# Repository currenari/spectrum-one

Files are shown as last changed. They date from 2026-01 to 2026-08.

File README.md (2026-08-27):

# Spectrum One

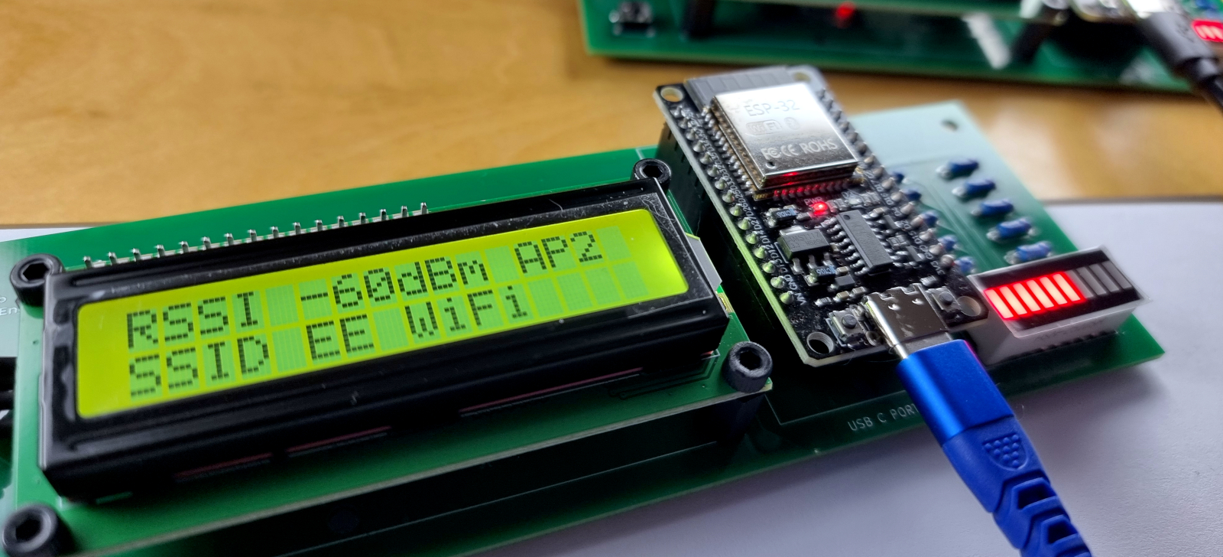
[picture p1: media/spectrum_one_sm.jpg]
Spectrum One


Spectrum One is a compact ESP32-based WiFi activity monitor that visualises nearby WiFi activity using a 16×2 LCD and a 10-segment LED bar.

It works by running repeated WiFi scans and turning the results into something you can actually see — live signal bars, changing numbers, blinking LEDs. The values shown are derived from WiFi RSSI and are intended for visualisation and comparison, not calibrated RF measurement.

This repository contains the reference implementation of the device.

---

## Open Hardware Certification

<a href="https://certification.oshwa.org/uk000086.html">
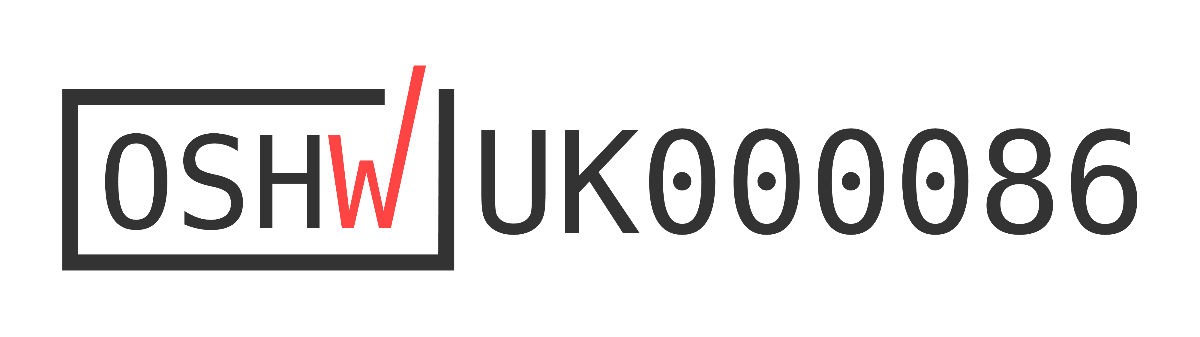
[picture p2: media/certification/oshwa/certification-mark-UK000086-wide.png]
OSHWA certification UK000086
  
</a>

**OSHWA UID:** UK000086  
Full record: `CERTIFICATION.md`  
Certified hardware version: 0.1.0

---

## Repository Contents

The repository is organised by release version and contains:

**binaries/**  
Versioned reference firmware binaries for flashing Spectrum One hardware.

**firmware/**  
ESP-IDF firmware source code.

**hardware/**  
KiCad schematics, PCB layouts, symbols, footprints, and fabrication outputs.

**docs/**  
Repository documentation, technical notes, and [ESP32 WiFi Activity Monitor PDF Book (Direct Download)](https://github.com/currenari/spectrum-one/raw/main/docs/ESP32%20WiFi%20Activity%20Monitor.pdf).

**media/**  
Images and diagrams used by the repository documentation.

---

## Hardware Assembly

This repository provides assembly documentation sufficient to reproduce the open hardware design.

General assembly information is provided in:

`ASSEMBLY.md`

Version-specific assembly notes are located under:

- `hardware/v0.1.0/ASSEMBLY.md`

---

## Project Scope

This repository contains the open hardware design files, firmware source code, reference binaries, and technical documentation required to reproduce Spectrum One.

Extended development notes and technical writing are published at:

https://currenari.com

---

## Licensing

Licensing is separated by material type:

- **Firmware source code and binaries**  
  MIT License

- **Hardware design files**  
  CERN Open Hardware Licence v2.0 – Strongly Reciprocal (CERN-OHL-S-2.0)

- **Repository documentation and media**  
  Creative Commons Attribution 4.0 International (CC BY 4.0)

Full licensing terms are defined in `LICENSE.md`.

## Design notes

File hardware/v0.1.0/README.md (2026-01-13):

# Spectrum One Hardware v0.1.0

This folder contains the KiCad design files for Spectrum One hardware release v0.1.0.

Contents include:
- Schematic
- PCB layout
- Custom symbols and footprints
- Fabrication outputs (Gerbers and drill files)

The Gerbers in hardware/v0.1.0/gerbers are the release fabrication set for this version.

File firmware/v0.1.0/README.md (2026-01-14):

# Spectrum One Firmware v0.1.0

This directory contains the firmware source for Spectrum One release v0.1.0,
implemented as an ESP-IDF application for the ESP32 platform.

The firmware is built and flashed using Espressif’s ESP-IDF toolchain, which is
the supported and documented development environment for this project.

Its function is to perform repeated WiFi scans and visualise observed activity
using an LCD and LED bar display.

## Build environment

ESP-IDF is the supported build environment.

## Notes

This firmware is intended to observe and visualise WiFi activity.
It does not provide calibrated RF measurements.

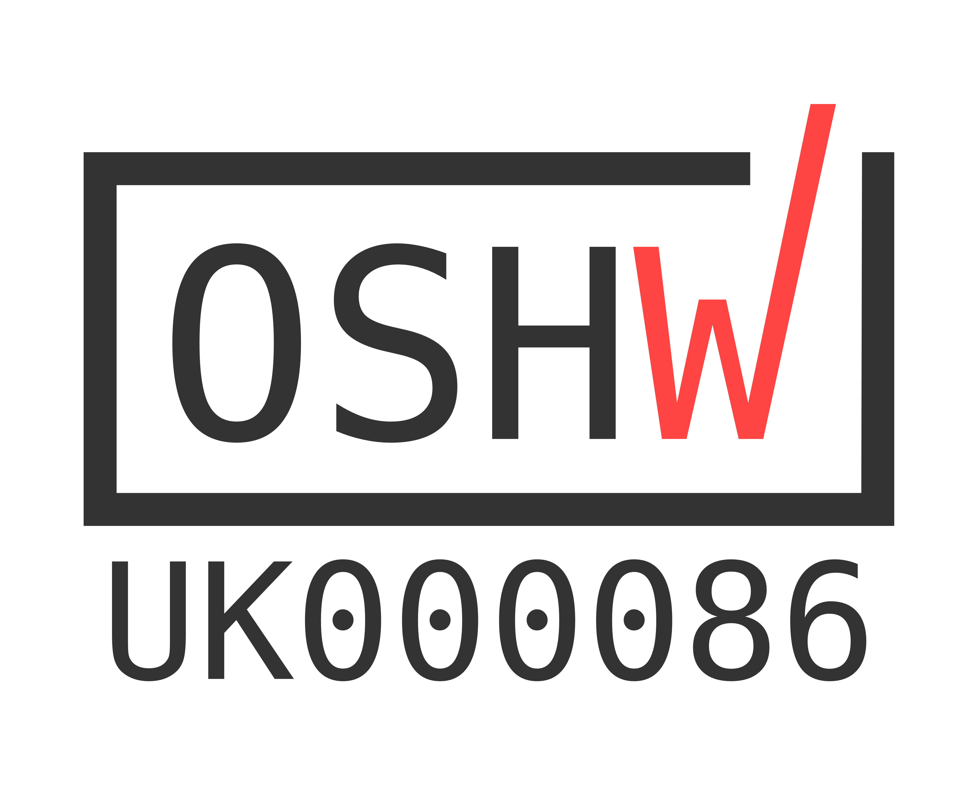
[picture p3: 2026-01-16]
media/certification/oshwa/certification-mark-UK000086-stacked.png

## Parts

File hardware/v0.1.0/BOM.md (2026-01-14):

# Spectrum One – Bill of Materials

This document lists the physical components used in the Spectrum One reference hardware.

The BOM reflects the exact parts and construction choices used during development and validation.
It is provided to support reproducibility of the hardware design. Equivalent parts with matching
specifications may be used unless otherwise noted.

---

## ESP32 Development Board (1×)

- Type: ESP32 Dev Kit V1
- Module: ESP32-WROOM-32
- Form factor: 30-pin
- USB interface: USB-C

---

## Pin Headers for ESP32 Development Board (2×)

- Type: pin header
- Pitch: 2.54 mm
- Positions: 15-pin
- Rows: single row
- Mounting: through-hole
- Use: PCB to ESP32 development board connection

---

## LCD 1602 Display with I2C Backpack (1×)

- Display type: LCD 1602
- Controller: HD44780 compatible
- Display format: 16 characters × 2 lines
- Native interface: parallel (HD44780)

### I2C backpack

- Controller: PCF8574
- Interface: I2C
- Pinout: GND, VCC, SDA, SCL
- Default I2C address: 0x27
- Address selection: configurable via A0, A1, A2 jumpers

---

## JST XH Connector and Cable Assembly

### PCB-mounted connector (1×)

- Type: JST XH series
- Pitch: 2.54 mm
- Positions: 4-pin
- Mounting: through-hole, soldered directly to the PCB
- Use: LCD power and I2C connection

### Cable assembly (1×)

- Type: JST XH compatible cable
- Configuration: 4-pin
- One end: JST XH housing (mates with PCB connector)
- Other end: individual wires soldered directly to the LCD I2C backpack
- Note: no connector fitted on the LCD side in the reference build

---

## LED Bar Graph Display (1×)

- Part type: LED bar graph
- Model: HSN-2510SR
- Colour: red
- Segment count: 10 independent LEDs
- Pin count: 20 pins (10 per side)
- Electrical configuration: no common anode, no common cathode

---

## Resistors (10×)

- Resistance: 220 Ω
- Tolerance: 5 percent
- Power rating: 0.25 W
- Type: through-hole axial

---

## Capacitor (1×)

- Capacitance: 100 nF
- Type: ceramic
- Package: through-hole
- Purpose: local supply decoupling

---

## Push Button (1×)

- Type: momentary tactile switch
- Configuration: SPST, normally open
- Package: through-hole, 6 × 6 mm

---

## Display Mounting Hardware

### Nylon standoffs (4×)

- Type: hexagonal PCB standoff
- Material: nylon
- Thread: M3, female–female
- Length: 10 mm
- Use: spacing and mounting of LCD module above PCB

### Nylon screws (8×)

- Type: socket cap head screw
- Material: nylon
- Thread: M3
- Length: 6 mm
- Drive: hex (Allen)
- Use: fixing LCD module to nylon standoffs

---

## LCD I2C Address Note

The reference build uses an LCD1602 with a PCF8574 I2C backpack configured at address `0x27`.

Some visually identical LCD backpacks use address `0x3F` instead.
If the display remains blank, change the firmware LCD address accordingly and rebuild.

This behaviour is covered in detail in the firmware documentation.

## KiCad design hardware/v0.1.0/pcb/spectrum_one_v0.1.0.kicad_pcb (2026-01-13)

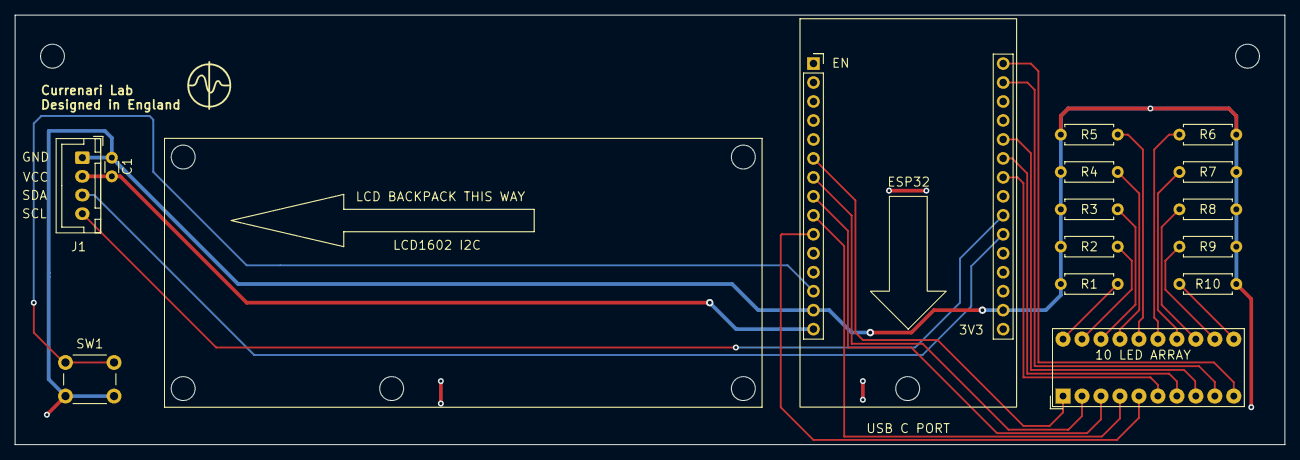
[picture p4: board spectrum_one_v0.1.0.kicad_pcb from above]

Board: 2 copper layers, 170.0 x 57.5 mm, 15 parts (0 on the bottom side), 25 nets.

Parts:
10 LED ARRAY: HLCP-J100_2; HLCP-J100
C1: C; C_Disc_D3.0mm_W1.6mm_P2.50mm
ESP32: Copper Keepout Zone; ESP32_DEVKIT_V1_DUAL_HEADER_SOCKET_VERTICAL
J1: LCD_I2C_XH4_PCBSocket; JST_XH_B4B-XH-A_1x04_P2.50mm_Vertical
R1, R2, R3, R4, R5, R6, R7, R8, R9, R10: R; R_Axial_DIN0207_L6.3mm_D2.5mm_P7.62mm_Horizontal
SW1: SW_Tact_6x6mm_H5mm_PxPy; SW_Tact_6x6mm_H5mm_PxPy_footprint

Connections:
/VCC: C1.2, ESP32.15 (VIN), J1.2 (VCC)
GND: C1.1, ESP32.14 (GND), ESP32.29 (GND), J1.1 (GND), R1.1, R2.1, R3.1, R4.1, R5.1, R6.1, R7.1, R8.1, R9.1, R10.1, SW1.2
unnamed: 10 LED ARRAY.11 (K), R10.2
unnamed: 10 LED ARRAY.12 (K), R9.2
unnamed: 10 LED ARRAY.13 (K), R8.2
unnamed: 10 LED ARRAY.14 (K), R7.2
unnamed: 10 LED ARRAY.15 (K), R6.2
unnamed: 10 LED ARRAY.16 (K), R5.2
unnamed: 10 LED ARRAY.17 (K), R4.2
unnamed: 10 LED ARRAY.18 (K), R3.2
unnamed: 10 LED ARRAY.19 (K), R2.2
unnamed: 10 LED ARRAY.20 (K), R1.2
unnamed: ESP32.24 (GPIO17), J1.4 (SCL)
unnamed: ESP32.25 (GPIO16), J1.3 (SDA)
unnamed: ESP32.13 (GPIO13), SW1.1
unnamed: 10 LED ARRAY.6 (A), ESP32.22 (GPIO18)
unnamed: 10 LED ARRAY.7 (A), ESP32.21 (GPIO19)
unnamed: 10 LED ARRAY.8 (A), ESP32.20 (GPIO21)
unnamed: 10 LED ARRAY.9 (A), ESP32.17 (GPIO22)
unnamed: 10 LED ARRAY.10 (A), ESP32.16 (GPIO23)
unnamed: 10 LED ARRAY.3 (A), ESP32.8 (GPIO25)
unnamed: 10 LED ARRAY.4 (A), ESP32.9 (GPIO26)
unnamed: 10 LED ARRAY.5 (A), ESP32.10 (GPIO27)
unnamed: 10 LED ARRAY.1 (A), ESP32.6 (GPIO32)
unnamed: 10 LED ARRAY.2 (A), ESP32.7 (GPIO33)

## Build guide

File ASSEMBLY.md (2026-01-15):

This repository provides minimal assembly documentation
to support reproduction of the Spectrum One hardware.

Version-specific assembly notes:
- hardware/v0.1.0/ASSEMBLY.md

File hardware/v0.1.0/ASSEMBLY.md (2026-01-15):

# Spectrum One PCB Assembly  
Hardware version v0.1.0

This document describes PCB level assembly requirements for the Spectrum One hardware.

## Scope
This document covers PCB level assembly.

Firmware, electrical behaviour, calibration, and end user operation are out of scope.

## Bill of Materials
All components, values, quantities, and reference designators are defined in the Bill of Materials.

**The BOM is the single source of truth for parts.**

See:
- `hardware/v0.1.0/BOM.md`

This assembly document does not repeat the component list in order to avoid duplication and inconsistency.

## Board overview
- 2 layer FR4 PCB
- ESP32 development module installed using soldered pin header sockets
- Power supplied via the ESP32 module USB C connector (5 V)
- 3.3 V logic throughout the board

## Assembly notes

### ESP32 module mounting
- Pin header sockets are soldered to the PCB
- The ESP32 module is inserted into the sockets after soldering
- The ESP32 module itself is not soldered directly to the PCB

### LED bar array orientation
- The LED bar is a single multi LED package with a fixed pinout
- The component must be installed in the correct orientation as a whole
- Orientation is defined by the PCB silkscreen and the package pin 1 marking
- Installing the LED bar in reverse orientation will prevent correct operation

### LCD backpack connection
- LCD1602 I2C backpacks may use different pinout arrangements depending on manufacturer
- Pin order must be verified before any direct electrical connection
- The recommended approach is to connect the LCD backpack to the PCB using four wires terminated with a JST connector
- This avoids pinout mismatch issues and allows easier replacement

### LCD mounting
- The LCD module is mounted with a 10 mm standoff distance at four mounting points
- Ensure the LCD is mechanically supported and not under strain after installation

### Orientation
- ESP32 module orientation follows the PCB silkscreen outline and arrow
- LCD related connectors must follow PCB silkscreen markings
- Pin 1 indicators must be respected where present

### Polarised components
- Polarised components must be oriented according to PCB markings

### Non polarised components
- Resistors and other non polarised passives may be installed in either orientation
- The capacitor located adjacent to the JST connector is non polarised and may be installed in either orientation

## Mechanical considerations
- Ensure pin header sockets are aligned and seated squarely before soldering
- Insert the ESP32 module only after all socket joints have cooled
- Avoid excessive heat on connectors, headers, and JST wiring
- Inspect all solder joints for wetting and continuity

## Reference files
- PCB layout: `pcb/`
- Schematic: `schematic/`
- Footprints: `footprints/`
- Symbols: `symbols/`
- Gerbers: `gerbers/`
- BOM: `BOM.md`

All reference files listed above correspond to hardware version v0.1.0.

## Assembly reference images

### Assembled PCB
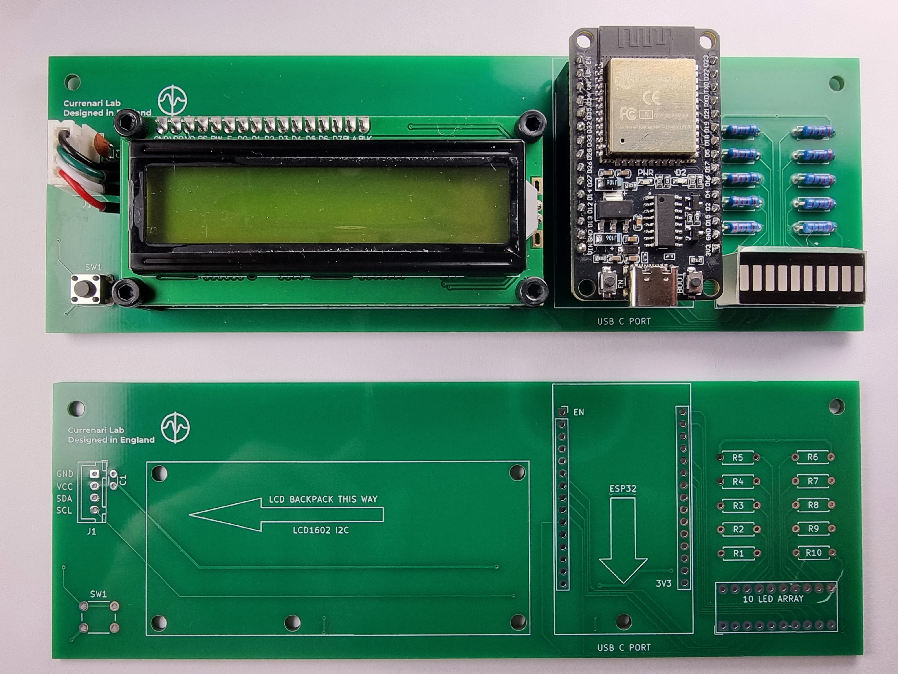
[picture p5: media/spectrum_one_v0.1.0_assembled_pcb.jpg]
Spectrum One assembled PCB v0.1.0


This image shows a fully assembled Spectrum One PCB for hardware version v0.1.0.

### Reference parts set
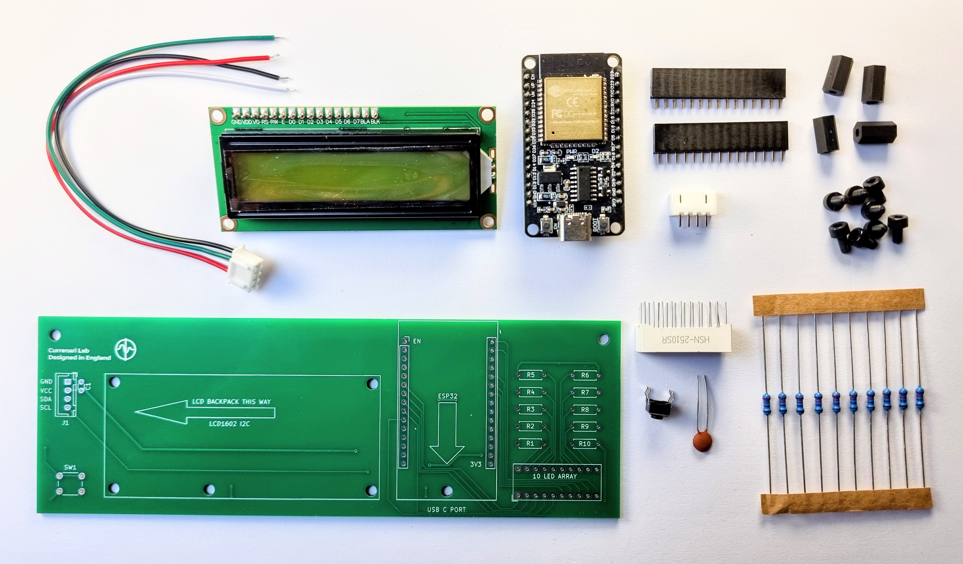
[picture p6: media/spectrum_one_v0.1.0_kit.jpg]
Spectrum One reference parts set v0.1.0


This image shows the physical components used in the reference build.
Equivalent parts meeting the BOM specifications may be used.

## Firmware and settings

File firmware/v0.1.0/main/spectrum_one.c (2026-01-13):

/**
 * @file spectrum_one.c
 *
 * Main application code for Spectrum One.
 *
 * Handles UI state, button input, display updates, and coordination
 * between WiFi scan results, the LCD, and the LED bar.
 *
 * UI modes:
 *   0 : Strongest access point (browse overlay when active)
 *   1 : Total power (SUM)
 *   2 : Field level
 *
 * Additional state flags control browsing and follow behaviour.
 *
 * Compile-time options below allow different timeout and interaction
 * behaviours to be tested.
 */


/*
 * Button response timing
 *
 * Button input is polled and debounced, then handled in the main loop.
 * This keeps UI state changes simple but adds noticeable latency.
 *
 * Delay comes from:
 * - Poll interval and debounce
 * - Event handling tied to the main loop timing
 *
 * Worst case response can be close to the main loop delay.
 *
 * If faster response is needed in a future revision:
 * - Lower debounce or poll interval
 * - Shorten the main loop delay
 * - Handle button events directly in the button task
 */



#include <stdio.h>
#include <stdbool.h>
#include <string.h>

#include "freertos/FreeRTOS.h"
#include "freertos/task.h"
#include "freertos/queue.h"

#include "esp_log.h"
#include "driver/gpio.h"

#include "led_bar.h"
#include "wifi_scan.h"
#include "lcd1602.h"
#include "wifi_one_math.h"
#include "config.h"

static const char *TAG = "SPECTRUM_ONE";

// -----------------------------------------------------------------------------
// Button and timing configuration
// -----------------------------------------------------------------------------

#define BTN_GPIO               SO_BUTTON_GPIO

#define BUTTON_POLL_MS         10
#define DEBOUNCE_TICKS         3
#define LONG_PRESS_MS          600

// -----------------------------------------------------------------------------
// UI behaviour options (compile-time)
// -----------------------------------------------------------------------------

/*
 * Main idle timeout.
 * When enabled, the UI returns to the Field screen after inactivity.
 */
#define UI_IDLE_TIMEOUT_ENABLED     0
#define UI_IDLE_TIMEOUT_MS          8000

/*
 * Browse timeout.
 * When enabled, browse mode exits automatically after a delay.
 */
#define UI_BROWSE_TIMEOUT_ENABLED   1
#define UI_BROWSE_TIMEOUT_MS        5000

/*
 * SUM screen timeout.
 * Independent timeout for the SUM screen only.
 */
#define UI_SUM_TIMEOUT_ENABLED      0
#define UI_SUM_TIMEOUT_MS           15000

/*
 * Short-click behaviour on SUM screen.
 * When enabled, a short click exits SUM directly to Field.
 */
#define UI_SUM_SHORTCLICK_EXITS     0

/* Internal compatibility mappings */
#define AP_BROWSE_TIMEOUT_MS        UI_BROWSE_TIMEOUT_MS
#define MAIN_IDLE_TIMEOUT_MS        UI_IDLE_TIMEOUT_MS

// -----------------------------------------------------------------------------
// UI event queue
// -----------------------------------------------------------------------------

typedef enum {
    UI_EVT_SHORT_CLICK = 0,
    UI_EVT_LONG_PRESS  = 1
} ui_evt_type_t;

typedef struct {
    ui_evt_type_t type;
    TickType_t    tick;
} ui_evt_t;

static QueueHandle_t ui_evt_q = NULL;

// -----------------------------------------------------------------------------
// UI state
// -----------------------------------------------------------------------------

/* 0 = strongest, 1 = SUM, 2 = Field */
static int ui_mode = 2;

static int        current_ap_index    = 0;
static bool       ap_browse_active    = false;
static TickType_t ap_browse_last_tick = 0;

static TickType_t last_activity_tick  = 0;
static TickType_t sum_enter_tick      = 0;

static wifi_scan_result_t last_scan_result;
static bool               last_scan_valid = false;

/* Follow mode state */
static bool follow_mode     = false;
static int  follow_ap_index = -1;
static char follow_ssid[33];

/* Button debounce and press tracking */
static int        btn_stable_state = 1;
static int        btn_debounce_cnt = 0;
static bool       btn_down         = false;
static bool       btn_long_handled = false;
static TickType_t btn_down_tick    = 0;

// -----------------------------------------------------------------------------
// Button handling
// -----------------------------------------------------------------------------

static void button_init(void)
{
    gpio_config_t io_conf = {
        .mode = GPIO_MODE_INPUT,
        .pull_up_en = GPIO_PULLUP_ENABLE,
        .pull_down_en = GPIO_PULLDOWN_DISABLE,
        .intr_type = GPIO_INTR_DISABLE,
        .pin_bit_mask = 1ULL << BTN_GPIO
    };

    gpio_config(&io_conf);

    btn_stable_state = 1;
    btn_debounce_cnt = 0;
    btn_down         = false;
    btn_long_handled = false;
}

static void ui_evt_send(ui_evt_type_t type, TickType_t now)
{
    if (ui_evt_q == NULL) return;

    ui_evt_t e = { .type = type, .tick = now };

/* Queue overflow drops events under heavy input */
    (void)xQueueSend(ui_evt_q, &e, 0);
}

// -----------------------------------------------------------------------------
// Display update logic
// -----------------------------------------------------------------------------

static void refresh_display(void)
{
    if (!last_scan_valid) {
        lcd_show_status("Scanning", "Please wait");
        led_bar_set_level(0);
        return;
    }

    /* Follow mode overrides all other UI states */
    if (follow_mode) {
        if (last_scan_result.ap_count == 0 ||
            follow_ap_index < 0 ||
            follow_ap_index >= last_scan_result.ap_count) {

            lcd_show_status("Locked AP", "Lost");
            led_bar_set_level(0);
            return;
        }

        const wifi_ap_info_t *ap = &last_scan_result.ap_records[follow_ap_index];

        lcd_show_scan_result(ap->rssi, follow_ap_index + 1, ap->ssid);
        led_bar_set_level(wifi_one_led_from_ap_rssi(ap->rssi));
        return;
    }

    if (last_scan_result.ap_count == 0) {
        lcd_show_status("No APs", "Scan again");
        led_bar_set_level(0);
        return;
    }

    int   led_level = 0;
    float field_nw  = wifi_one_field_from_mw(last_scan_result.total_mw);

    if (ui_mode == 0) {
        if (ap_browse_active) {
            if (current_ap_index >= last_scan_result.ap_count) {
                current_ap_index = 0;
            }

            const wifi_ap_info_t *ap =
                &last_scan_result.ap_records[current_ap_index];

            lcd_show_scan_result(ap->rssi,
                                 current_ap_index + 1,
                                 ap->ssid);

            led_level = wifi_one_led_from_ap_rssi(ap->rssi);

        } else {
            lcd_show_scan_result(last_scan_result.best_rssi,
                                 last_scan_result.ap_count,
                                 last_scan_result.best_ssid);

            led_level = wifi_one_led_from_field(field_nw);
        }

    } else if (ui_mode == 1) {
        lcd_show_total_power(last_scan_result.total_dbm,
                             last_scan_result.total_mw);
        led_level = wifi_one_led_from_field(field_nw);

    } else {
        lcd_show_field_level(field_nw);
        led_level = wifi_one_led_from_field(field_nw);
    }

    led_bar_set_level(led_level);
}

// -----------------------------------------------------------------------------
// UI event handlers
// -----------------------------------------------------------------------------

static void handle_short_click(TickType_t now)
{
    last_activity_tick = now;

    if (ap_browse_active &&
        last_scan_valid &&
        last_scan_result.ap_count > 0) {

        current_ap_index++;
        if (current_ap_index >= last_scan_result.ap_count) {
            current_ap_index = 0;
        }

        ap_browse_last_tick = now;
        refresh_display();
        return;
    }

#if UI_SUM_SHORTCLICK_EXITS
    if (ui_mode == 1) {
        ui_mode = 2;
        refresh_display();
        return;
    }
#endif

    if (ui_mode == 2) {
        ui_mode = 0;
    } else if (ui_mode == 0) {
        ui_mode = 1;
        sum_enter_tick = now;
    } else {
        ui_mode = 2;
    }

    if (ui_mode != 0) {
        ap_browse_active = false;
    }

    refresh_display();
}

static void handle_long_press(TickType_t now)
{
    last_activity_tick = now;

    if (follow_mode) {
        follow_mode      = false;
        follow_ap_index  = -1;
        follow_ssid[0]   = '\0';
        ap_browse_active = false;
        ui_mode          = 2;

        refresh_display();
        return;
    }

    if (ap_browse_active &&
        last_scan_valid &&
        last_scan_result.ap_count > 0) {

        const wifi_ap_info_t *ap =
            &last_scan_result.ap_records[current_ap_index];

        follow_mode     = true;
        follow_ap_index = current_ap_index;

        if (ap->ssid[0] != '\0') {
            strncpy(follow_ssid,
                    ap->ssid,
                    sizeof(follow_ssid) - 1);
            follow_ssid[sizeof(follow_ssid) - 1] = '\0';
        } else {
            follow_ssid[0] = '\0';
        }

        ap_browse_active = false;
        refresh_display();
        return;
    }

    if (last_scan_valid && last_scan_result.ap_count > 0) {
        ui_mode          = 0;
        ap_browse_active = true;

        if (current_ap_index >= last_scan_result.ap_count) {
            current_ap_index = 0;
        }

        ap_browse_last_tick = now;
        refresh_display();
    }
}

// -----------------------------------------------------------------------------
// Button polling task
// -----------------------------------------------------------------------------

static void button_task(void *arg)
{
    (void)arg;

    while (1) {
        TickType_t now = xTaskGetTickCount();

        int raw = gpio_get_level(BTN_GPIO);

        if (raw == btn_stable_state) {
            btn_debounce_cnt = 0;
        } else if (++btn_debounce_cnt >= DEBOUNCE_TICKS) {
            btn_stable_state = raw;
            btn_debounce_cnt = 0;
        }

        int state = btn_stable_state;

        if (state == 0 && !btn_down) {
            btn_down         = true;
            btn_long_handled = false;
            btn_down_tick    = now;
        }

        if (state == 0 && btn_down && !btn_long_handled) {
            if ((now - btn_down_tick) > pdMS_TO_TICKS(LONG_PRESS_MS)) {
                btn_long_handled = true;
                ui_evt_send(UI_EVT_LONG_PRESS, now);
            }
        }

        if (state == 1 && btn_down) {
            btn_down = false;
            if (!btn_long_handled) {
                ui_evt_send(UI_EVT_SHORT_CLICK, now);
            }
        }

        vTaskDelay(pdMS_TO_TICKS(BUTTON_POLL_MS));
    }
}

// -----------------------------------------------------------------------------
// Application entry point
// -----------------------------------------------------------------------------

void app_main(void)
{
    led_bar_init();
    lcd_init();
    vTaskDelay(pdMS_TO_TICKS(1000));

    wifi_scan_init();
    button_init();

    ui_evt_q = xQueueCreate(8, sizeof(ui_evt_t));

    lcd_show_welcome();

    ui_mode            = 2;
    last_activity_tick = xTaskGetTickCount();
    sum_enter_tick     = last_activity_tick;
    follow_ssid[0]     = '\0';

    xTaskCreate(button_task, "button_task", 2048, NULL, 5, NULL);

    while (1) {
        ui_evt_t e;
        while (ui_evt_q &&
               xQueueReceive(ui_evt_q, &e, 0) == pdTRUE) {

            if (e.type == UI_EVT_SHORT_CLICK) {
                handle_short_click(e.tick);
            } else {
                handle_long_press(e.tick);
            }
        }

#if UI_BROWSE_TIMEOUT_ENABLED
        TickType_t now = xTaskGetTickCount();

        if (ap_browse_active &&
            (now - ap_browse_last_tick) >
            pdMS_TO_TICKS(AP_BROWSE_TIMEOUT_MS)) {

            ap_browse_active = false;
            ui_mode          = 2;
            refresh_display();
        }
#endif

#if UI_SUM_TIMEOUT_ENABLED
        if (!follow_mode &&
            !ap_browse_active &&
            ui_mode == 1 &&
            (xTaskGetTickCount() - sum_enter_tick) >
            pdMS_TO_TICKS(UI_SUM_TIMEOUT_MS)) {

            ui_mode = 2;
            refresh_display();
        }
#endif

#if UI_IDLE_TIMEOUT_ENABLED
        if (!follow_mode &&
            !ap_browse_active &&
            ui_mode != 2 &&
            (xTaskGetTickCount() - last_activity_tick) >
            pdMS_TO_TICKS(MAIN_IDLE_TIMEOUT_MS)) {

            ui_mode = 2;
            refresh_display();
        }
#endif

        wifi_scan_result_t result;

        if (follow_mode) {
            if (wifi_scan_run(&result)) {
                last_scan_result = result;
                last_scan_valid  = true;

                follow_ap_index = -1;

                for (int i = 0; i < result.ap_count; i++) {
                    const wifi_ap_info_t *ap =
                        &result.ap_records[i];

                    if (ap->ssid[0] &&
                        strncmp(ap->ssid,
                                follow_ssid,
                                sizeof(follow_ssid)) == 0) {

                        follow_ap_index = i;
                        break;
                    }
                }

            } else {
                last_scan_valid = false;
                follow_mode     = false;
                follow_ap_index = -1;
                follow_ssid[0]  = '\0';
            }

        } else if (!ap_browse_active) {
            if (wifi_scan_run(&result)) {
                last_scan_result = result;
                last_scan_valid  = true;
            } else {
                last_scan_valid   = false;
                ap_browse_active  = false;
                follow_mode       = false;
                follow_ap_index   = -1;
                follow_ssid[0]    = '\0';
            }
        }

        refresh_display();
        vTaskDelay(pdMS_TO_TICKS(500));
    }
}

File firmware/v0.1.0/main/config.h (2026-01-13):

#ifndef SPECTRUM_ONE_CONFIG_H
#define SPECTRUM_ONE_CONFIG_H

/*
 * Spectrum One hardware configuration.
 * Reference build: v0.1.0
 */

#include "driver/gpio.h"
#include "driver/i2c.h"

/* ---------------- I2C LCD ---------------- */

/* I2C configuration for LCD1602 backpack */
#define SO_I2C_PORT        I2C_NUM_0
#define SO_I2C_SDA_GPIO    16
#define SO_I2C_SCL_GPIO    17
#define SO_I2C_FREQ_HZ     100000

/* PCF8574 I2C address */
#define SO_LCD_ADDR        0x27

/* ---------------- User input ---------------- */

/* Active-low push button */
#define SO_BUTTON_GPIO     GPIO_NUM_13

/* ---------------- LED bar graph ---------------- */

/* 10-segment LED bar graph GPIO mapping */
#define SO_LED1_GPIO       GPIO_NUM_32
#define SO_LED2_GPIO       GPIO_NUM_33
#define SO_LED3_GPIO       GPIO_NUM_25
#define SO_LED4_GPIO       GPIO_NUM_26
#define SO_LED5_GPIO       GPIO_NUM_27
#define SO_LED6_GPIO       GPIO_NUM_18
#define SO_LED7_GPIO       GPIO_NUM_19
#define SO_LED8_GPIO       GPIO_NUM_21
#define SO_LED9_GPIO       GPIO_NUM_22
#define SO_LED10_GPIO      GPIO_NUM_23

#endif /* SPECTRUM_ONE_CONFIG_H */

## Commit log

2026-01-13 Initial Spectrum One v0.1.0
    [spectrum_one_v0.1.0-B_Cu.gbr, spectrum_one_v0.1.0-B_Mask.gbr, spectrum_one_v0.1.0-B_Silkscreen.gbr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]
2026-01-13 Update README to reflect current repository structure
2026-01-13 Add overview and versioned READMEs; fix pcb folder name
    [spectrum_one_v0.1.0.kicad_pcb]
2026-01-14 update BOM: complete hardware listing
2026-01-15 add assembly docs and photos
2026-01-15 update PCB assembly documentation
2026-02-09 Revise licensing terms and clarify book distribution
    Updated README and LICENSE to reflect the book now available as a free PDF/EPUB download at currenari.com/spectrum-one under Creative Commons Attribution–NonCommercial–ShareAlike 4.0.
2026-02-09 README update — book second edition free release under CC BY-NC-SA 4.0
    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
2026-08-27 Add ESP32 WiFi Activity Monitor PDF documentation
